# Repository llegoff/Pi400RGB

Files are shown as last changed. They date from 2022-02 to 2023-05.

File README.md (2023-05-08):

[:fr:](LISEZMOI.md) [:uk:](README.md)

# Pi400RGB
Scart/VGA interface for Raspberry Pi 400

Evolution of VGA_Zero (https://github.com/llegoff/VGA_Zero) and Pi400VGA (https://github.com/llegoff/Pi400VGA)

buy V2 on [ebay  :package: :credit_card:](https://www.ebay.fr/itm/404280189035)

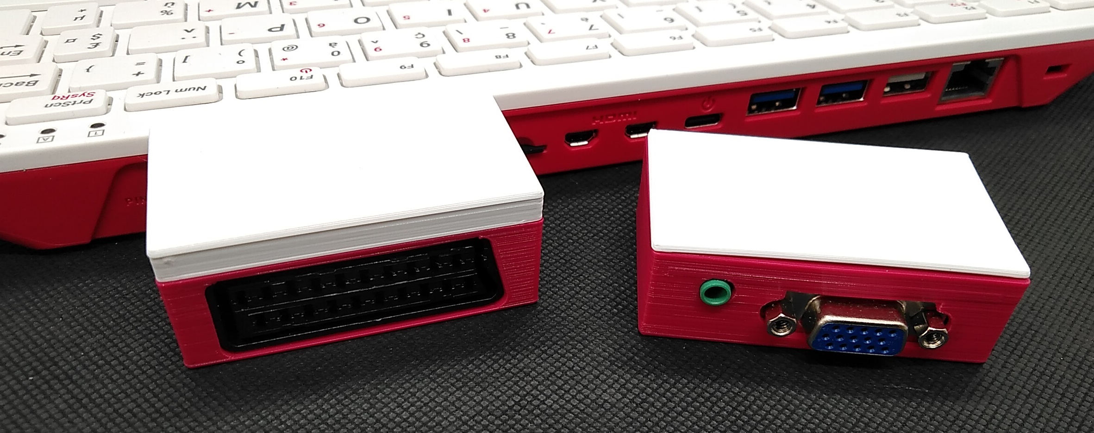
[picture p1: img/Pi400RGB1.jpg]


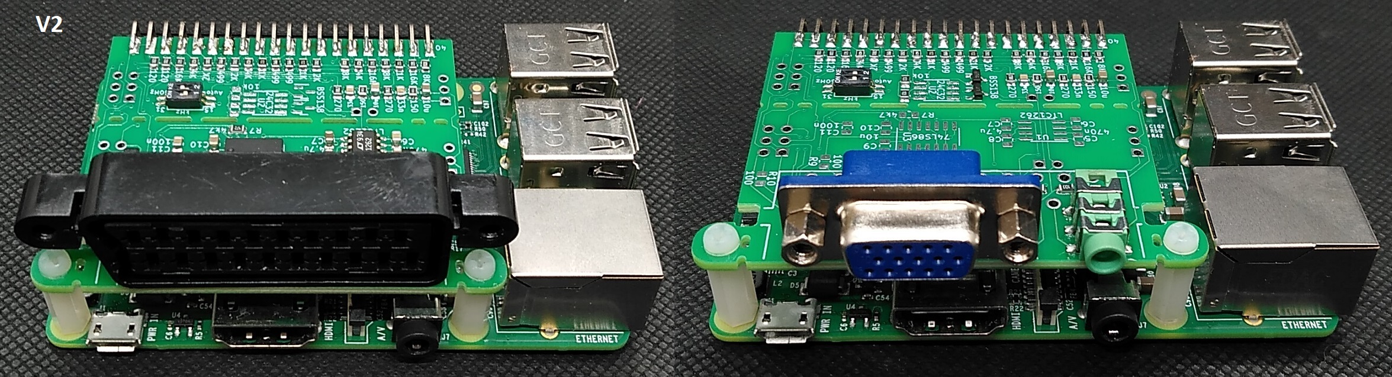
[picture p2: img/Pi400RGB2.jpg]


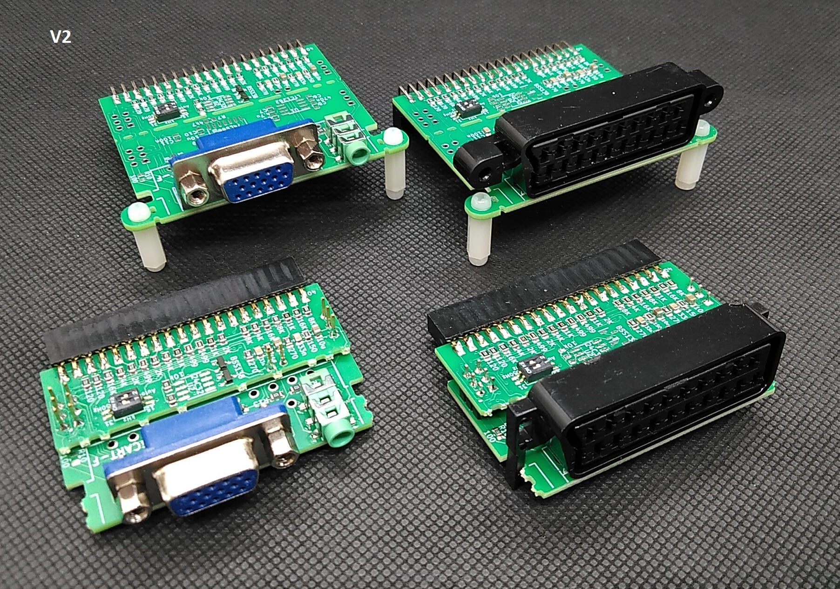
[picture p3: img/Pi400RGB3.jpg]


### DPI (Display parallel Interface)
Like [VGA666](https://github.com/fenlogic/vga666), this pcb uses dpi interface (in mode 6 to free gpio 18 & 19)

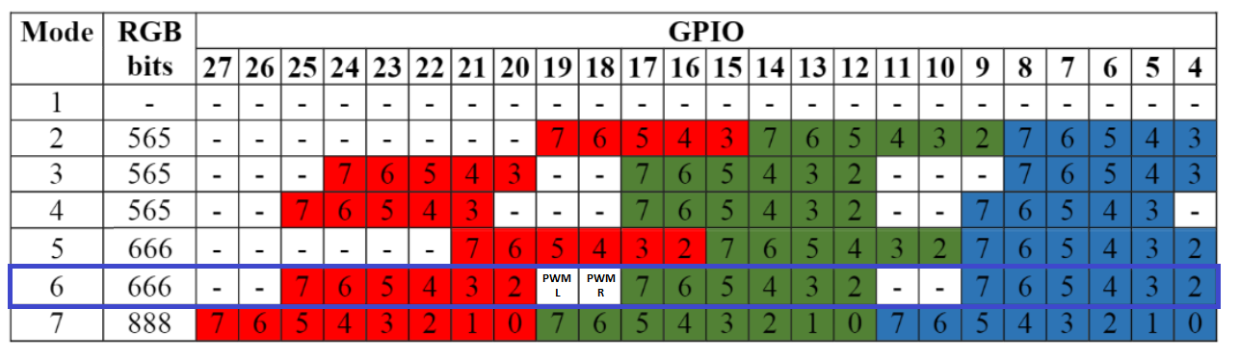
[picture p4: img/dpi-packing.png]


see https://www.raspberrypi.org/documentation/hardware/raspberrypi/dpi/README.md

only the necessary bits of the dpi are redirected to the 40-pin GPIO port, with the 'gpio=2-9,12-17,20-25=a2' line on config.txt

/boot/config.txt

    # disable i2c, pin use by h-sync & v-sync
    dtparam=i2c_arm=off
    # remplace dtoverlay=vc4-kms-v3d by
    dtoverlay=vc4-fkms-v3d
    #configuration DPI
    gpio=2-9,12-17,20-24=a2
    dpi_output_format=0x6
    enable_dpi_lcd=1
    display_default_lcd=1
    dpi_group=2
    dpi_mode=16
    #---------------- dpi_mode line VGA ---------------------
    #---> 640x480 60hz    dpi_mode=4
    #---> 800x600 60hz    dpi_mode=9
    #---> 1024x768 60hz   dpi_mode=16
    #---> 1280x768 60hz   dpi_mode=23
    #---> 1280x800 60hz   dpi_mode=28
    #---> 1280x960 60hz   dpi_mode=32
    #---> 1280x1024 60hz  dpi_mode=35
    #---> 1360x768 60hz   dpi_mode=39
    #---> 1366x768 60hz   dpi_mode=81
    #---> 1400x1050 60hz  dpi_mode=42
    #---> 1440x900 60hz   dpi_mode=47
    #---> 1600x1200 60hz  dpi_mode=51
    #---> 1680x1050 60hz  dpi_mode=58
    #---> 1920x1080 60hz  dpi_mode=82
    #---> 1920x1200 60hz  dpi_mode=69
    #---> 1920x1440 60hz  dpi_mode=73    
    #--------------- dpi_mode line SCART ------------------
    dpi_mode=87
    #240p@60
    #hdmi_timings=320 1 4 30 46 240 1 4 5 14 0 0 0 60 0 6400000 1
    #288p@50
    #hdmi_timings=384 1 16 32 40 288 1 3 2 19 0 0 0 50 0 7363200 1
    #576i@50
    hdmi_timings=768 1 24 72 88 576 1 6 5 38 0 0 0 50 1 14875000 1
    #480i@60
    #hdmi_timings=640 1 24 64 104 480 1 3 6 34 0 0 0 60 1 13054080 1
    #480p@60
    #hdmi_timings=640 1 24 96 48 480 1 11 2 32 0 0 0 60 0 25452000 1

Configuration working with vc4-kms-v3d

    dtoverlay=vc4-kms-dpi-generic,rgb666-padhi
    dtparam=hactive=768,hfp=24,hsync=72,hbp=88
    dtparam=vactive=576,vfp=6,vsync=5,vbp=38
    dtparam=clock-frequency=14875000
    #   Resolution@freq  hactive hfp hsync  hbp vactive vfp vsync vbp  clock-frequency
    #VGA   640x480  @60   640     16   96    48   480    10   2    33    25175000
    #SVGA  800x600  @60   800     40  128    88   600     1   4    23    40000000
    #XGA  1024x768  @60  1024     24  136   160   768     3   6    29    65000000
    #VESA 1368x768  @60  1368     72  144   216   768     1   3    23    85860000
    #VESA 1280x800  @60  1280     64  136   200   800     1   3    24    83460000
    #VESA 1280x1024 @60  1280     48  112   248  1024     1   3    38   108000000
    #VESA 1400x1050 @60  1400     88  152   240  1050     1   3    33   122660000
    #VESA 1600x1200 @60  1600     64  192   304  1200     1   3    46   162000000
    #--- TV -----
    #240p (NTSC res)@60   320      4   30    46   240     4   5    14     6400000
    #288p (PAL res) @50   384     16   32    40   288     3   2    19     7363200
    #480p           @60   640     24   96    48   480    11   2    32    25452000
    #720p           @60  1280    110   40   220   720     5   5    20    74250000
    #1080p          @60  1920     88   44   148  1080     4   5    36   148500000
    #more timming on http://tinyvga.com/vga-timing

### Audio Interface
audio interface is connected to gpio 18 & 19 (PWM)

/boot/config.txt

    # Enable audio for PiZero(loads snd_bcm2835)
    dtoverlay=audremap,pins_18_19
    dtparam=audio=on

### Recalbox

edit the config file /crt/recalbox-crt-options.cfg in the [RECALBOX] partition mounted when you plug the SD card in your computer:

see manual : https://www.recalbox.com/recalbox-rgb-dual/manual/

edit the config file /crt/recalbox-crt-options.cfg

    # Pour recalboxrgbdual
    adapter.type = recalboxrgbdual

the first boot can take 5 minutes

https://wiki.recalbox.com/en/tutorials/video/crt/recalbox-on-crt-with-scart-dac

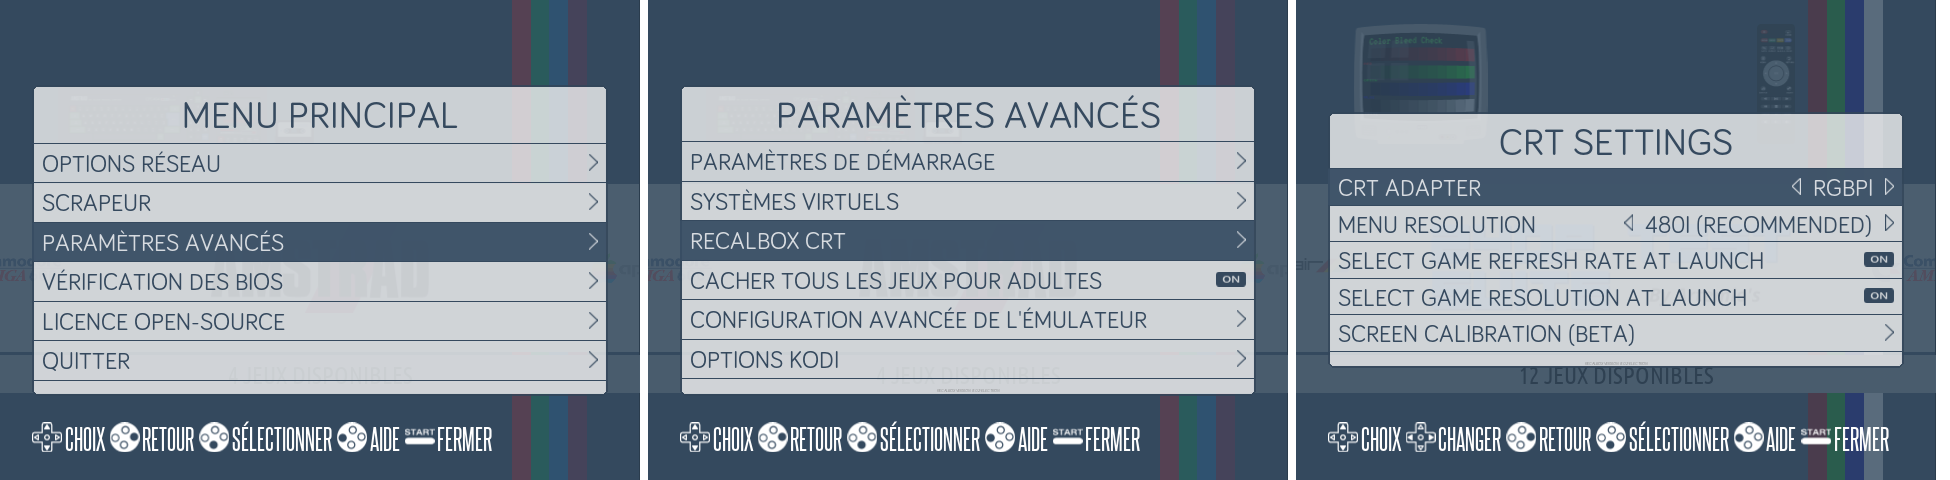
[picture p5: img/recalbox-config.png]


Add a jumper on V1 PCB

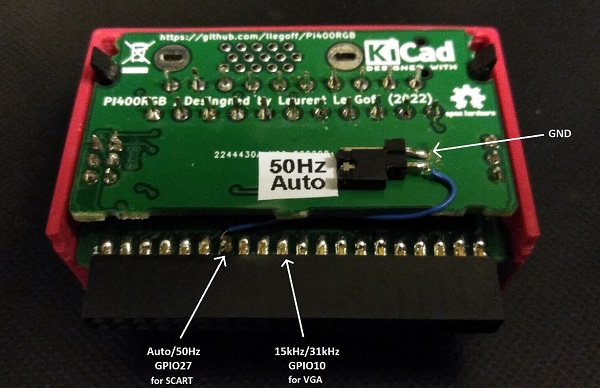
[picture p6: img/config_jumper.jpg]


## Schematic
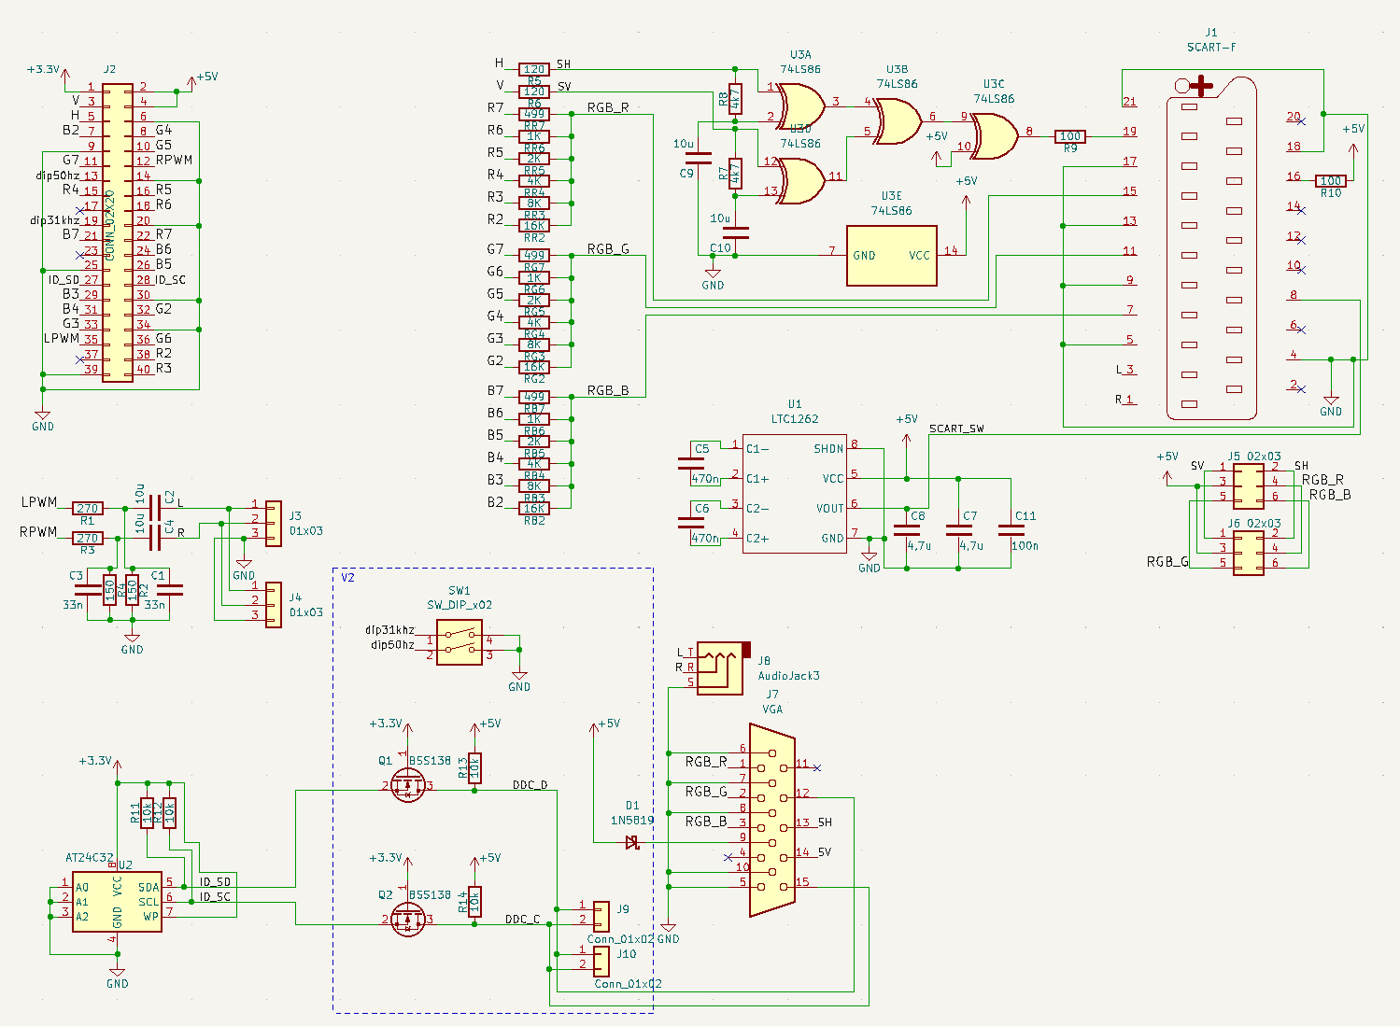
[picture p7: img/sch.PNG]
sch


## PCB
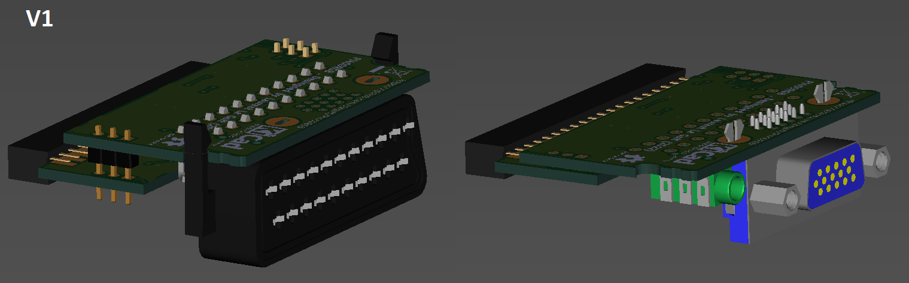
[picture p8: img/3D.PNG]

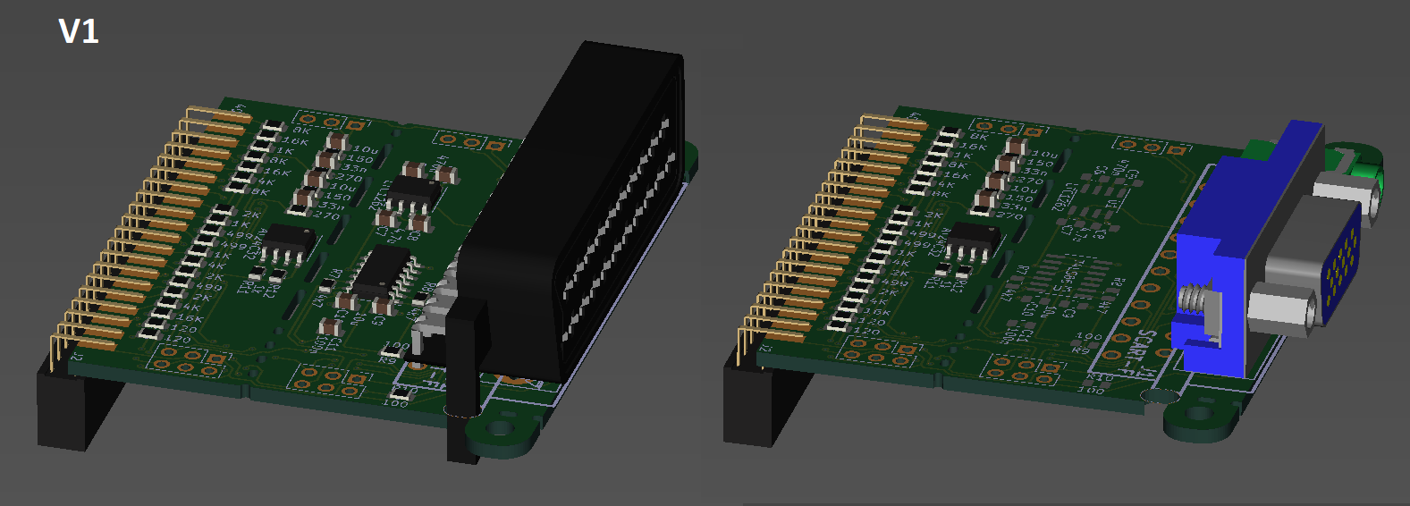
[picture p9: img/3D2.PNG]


## Installation
copy content of [config-example.txt](img/config-example.txt?raw=true) to /boot/config.txt

## Révision
rev1 : initial version

rev2 : add DDC on VGA connector and dip switch for recalbox configuration, coming soon

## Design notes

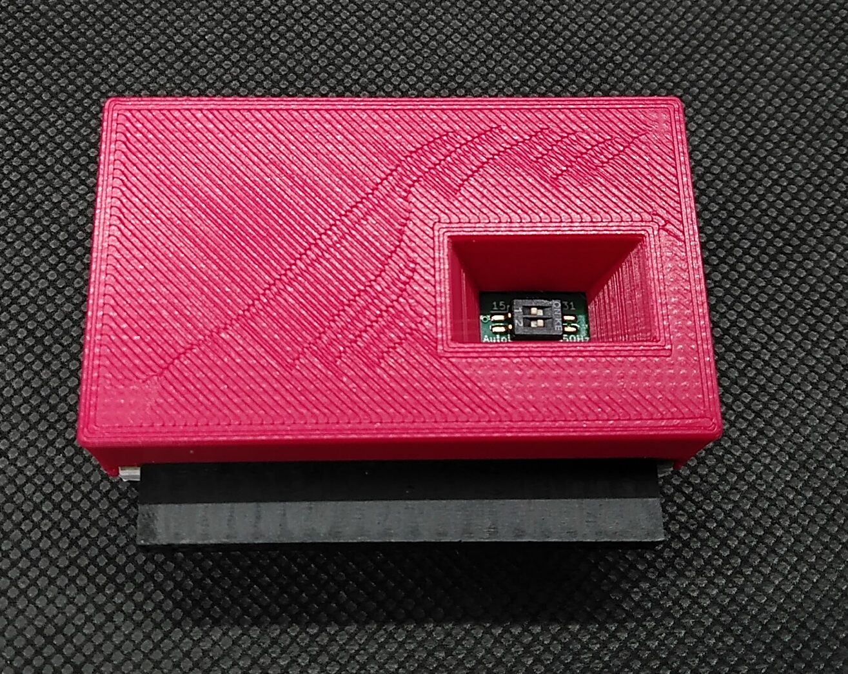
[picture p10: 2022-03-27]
img/PI400RGB5.jpg

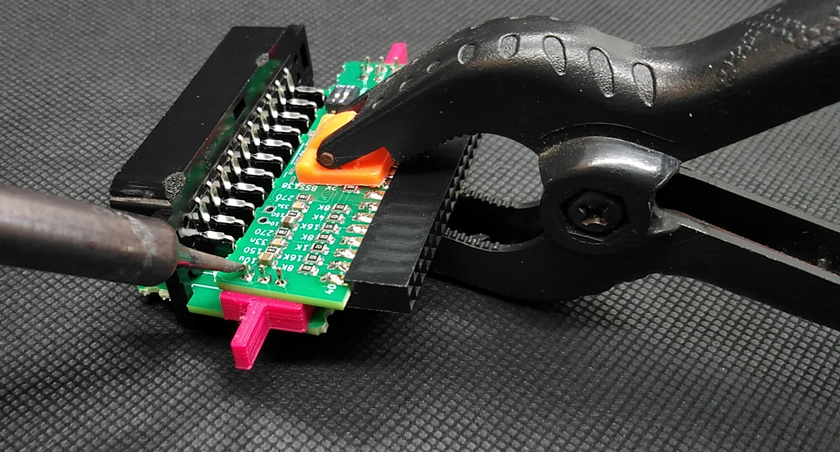
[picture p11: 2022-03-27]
img/PI400RGB4.jpg

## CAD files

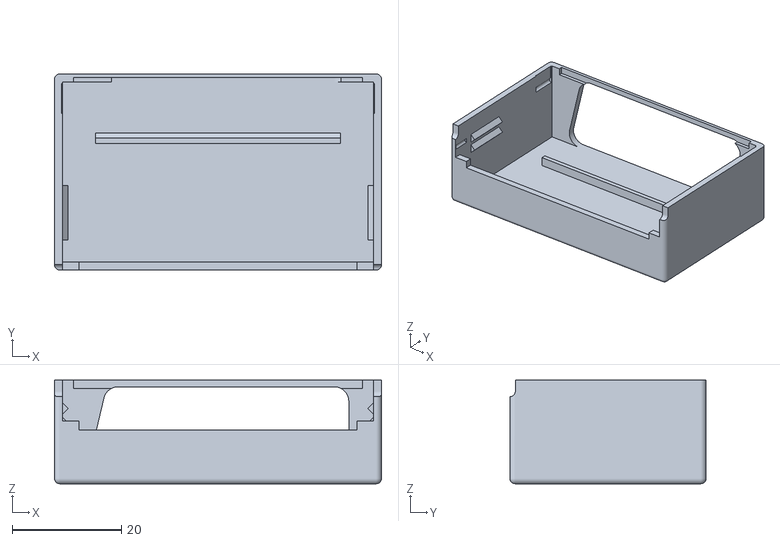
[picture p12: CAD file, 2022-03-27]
3D/Pi400RGB_SCARTbottom.stl
60.0 x 36.0 x 19.0

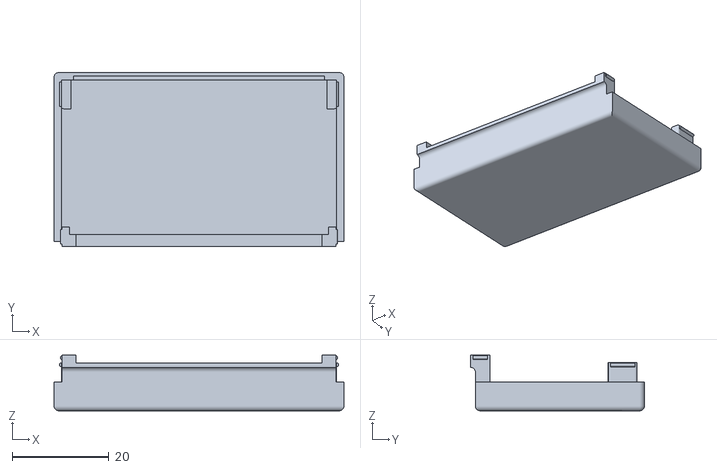
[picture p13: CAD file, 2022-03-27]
3D/Pi400RGB_SCARTtop.stl
60.0 x 36.0 x 11.5

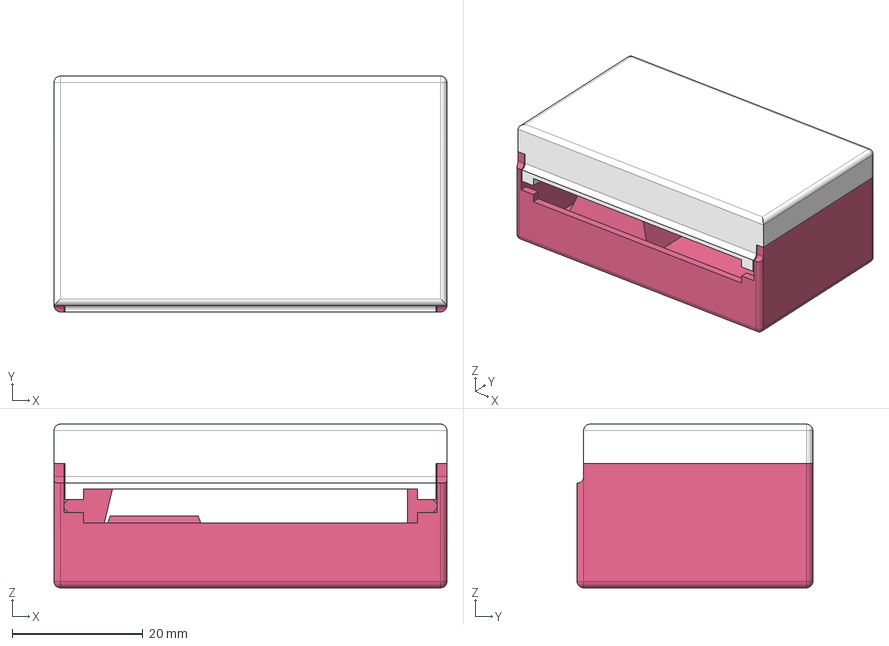
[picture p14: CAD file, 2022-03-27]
3D/Pi400RGB_Scart_V2.FCStd
60.0 x 36.0 x 25.0 mm

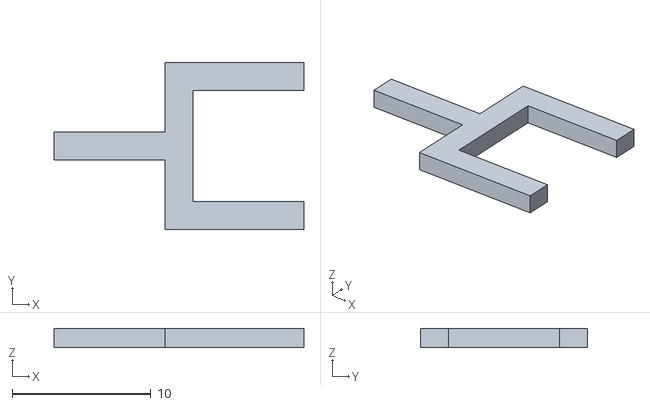
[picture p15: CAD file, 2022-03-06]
3D/VGA_Mounting_JIG.stl
18.0 x 12.0 x 1.40

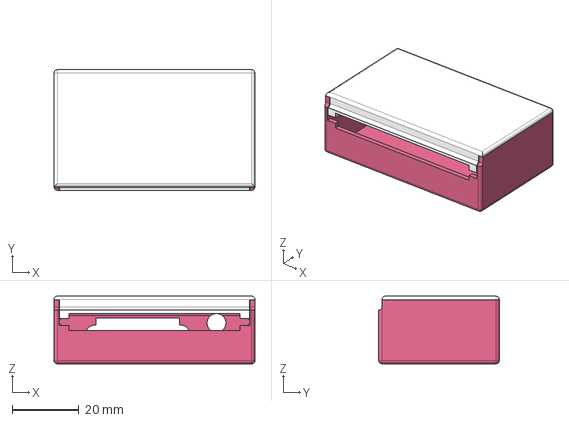
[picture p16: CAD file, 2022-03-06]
3D/Pi400RGB_VGA.FCStd
60.0 x 36.0 x 20.2 mm

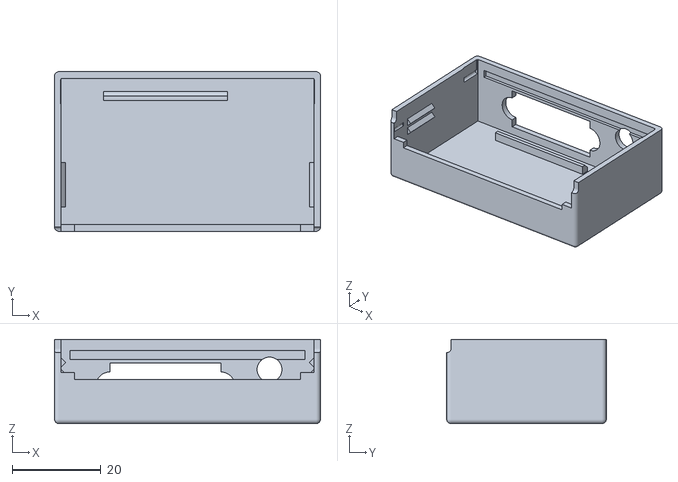
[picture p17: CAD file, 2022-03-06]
3D/Pi400RGB_VGAbottom.stl
60.0 x 36.0 x 19.0

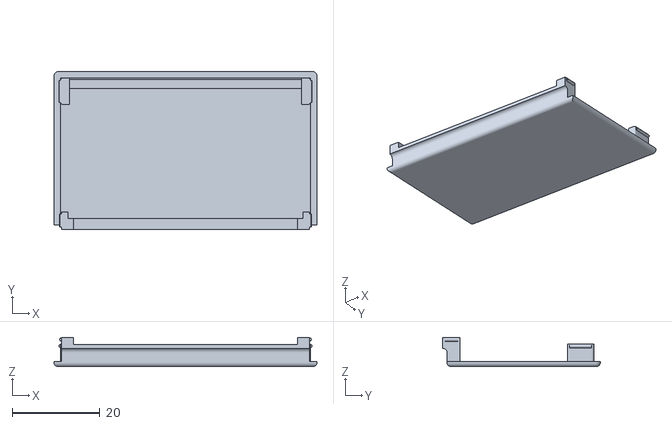
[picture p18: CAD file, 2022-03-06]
3D/Pi400RGB_VGAtop.stl
60.0 x 36.0 x 6.70

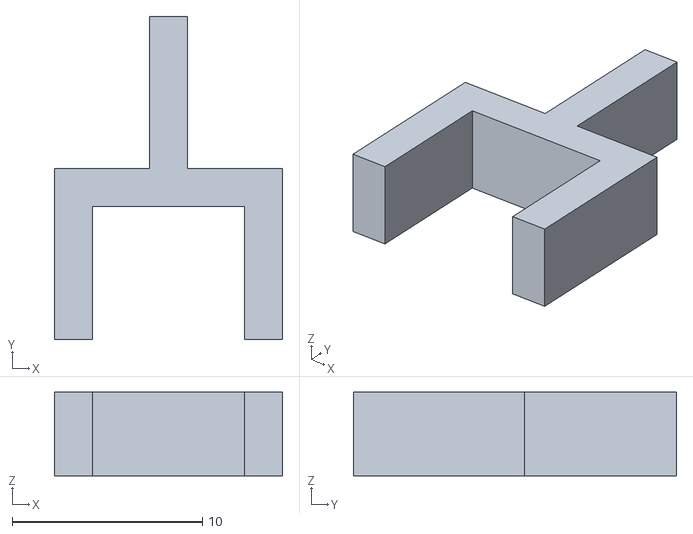
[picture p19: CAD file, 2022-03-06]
3D/Scart_Mounting_JIG.stl
12.0 x 17.0 x 4.40

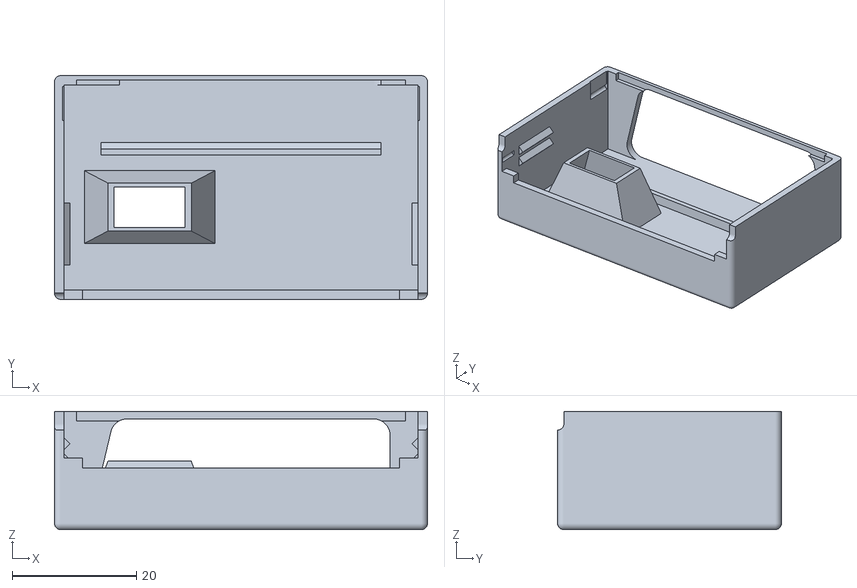
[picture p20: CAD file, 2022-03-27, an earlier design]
3D/Pi400RGB_SCARTbottomV2.stl
60.0 x 36.0 x 19.0

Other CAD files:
3D/Pi400RGB_Scart.FCStd

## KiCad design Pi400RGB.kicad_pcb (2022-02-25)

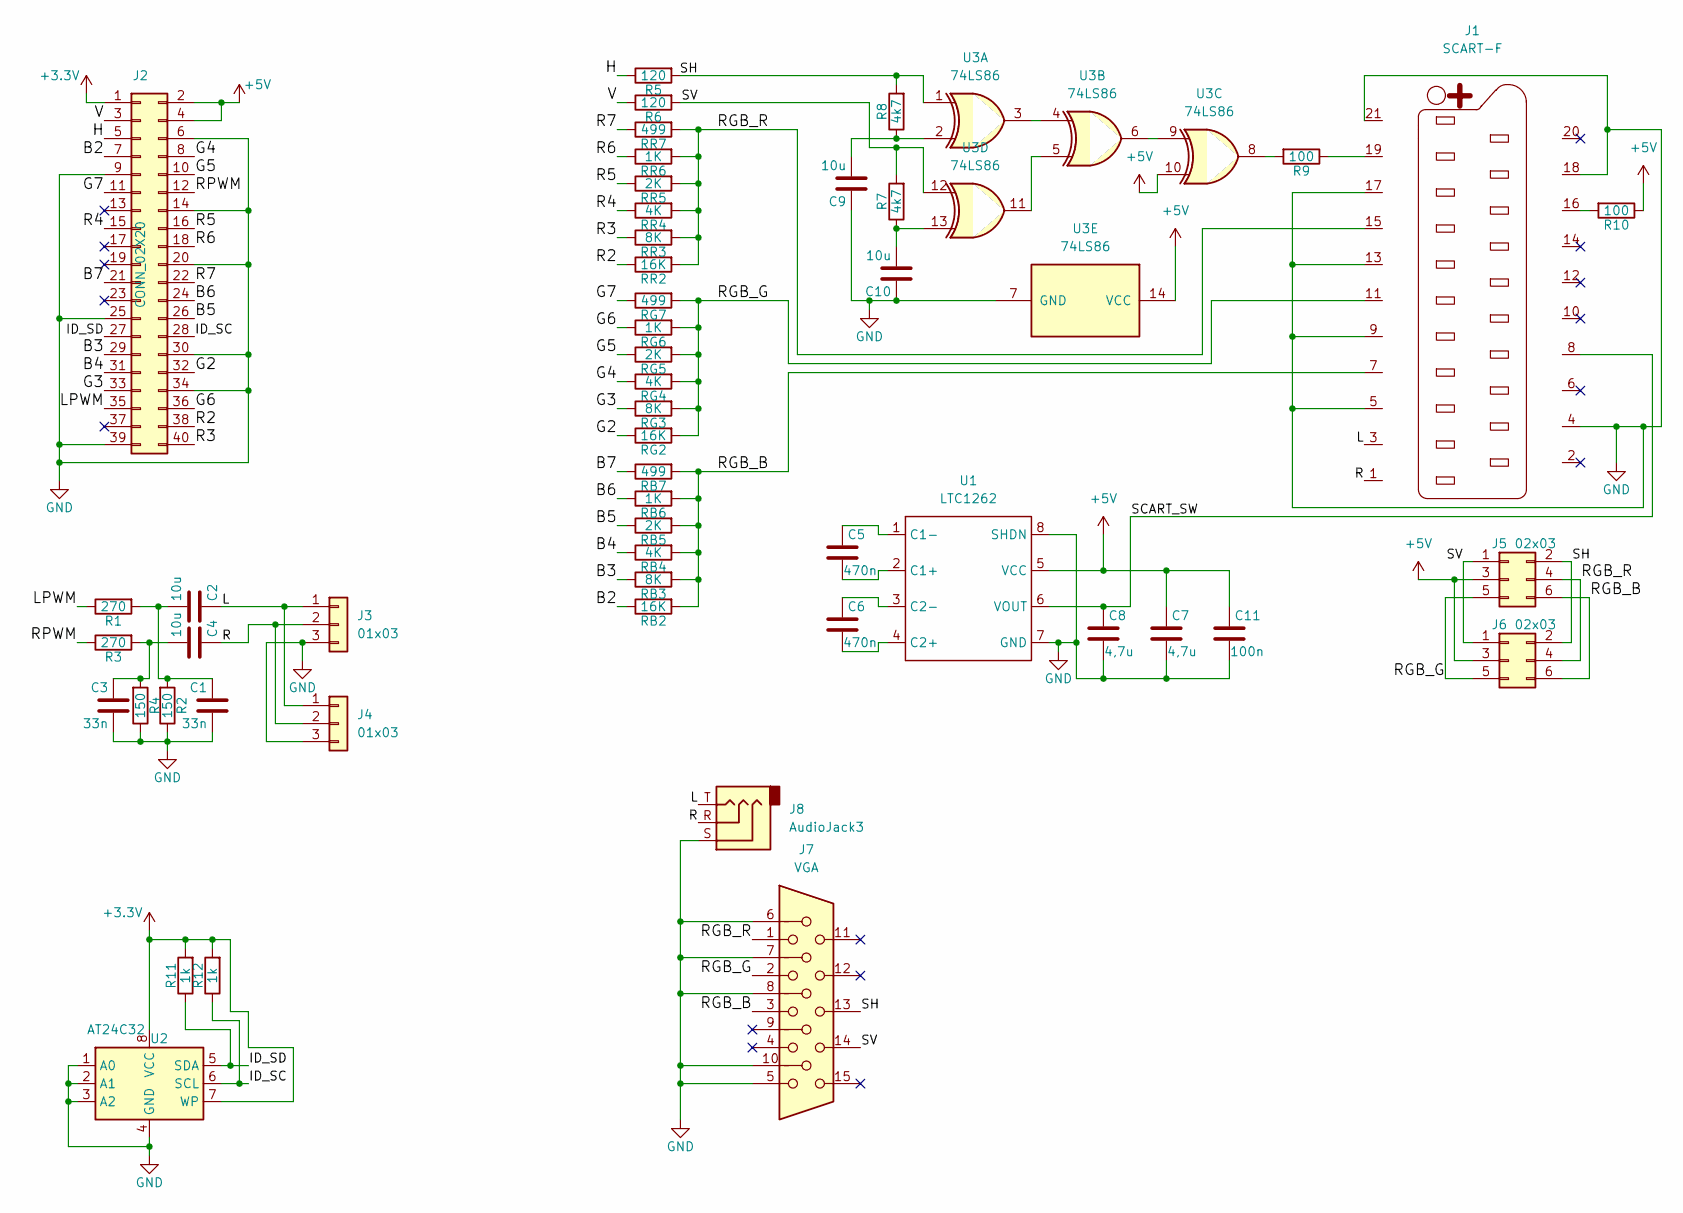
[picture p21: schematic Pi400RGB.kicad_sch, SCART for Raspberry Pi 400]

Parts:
C1, C3: 33n; C_0805_2012Metric
C2, C4, C9, C10: 10u; C_0805_2012Metric
C5, C6: 470n; C_0805_2012Metric
C7, C8: 4,7u; C_0805_2012Metric
C11: 100n; C_0805_2012Metric
J1: SCART-F; SCART
J2: CONN_02X20; 2x40_PCB
J3, J4: 01x03; PinHeader_1x03_P2.54mm_Vertical
J5, J6: 02x03; PinHeader_2x03_P2.54mm_Vertical
J7: VGA; DB_15F-VGA
J8: AudioJack3; jack3.5smd
R1, R3: 270; R_0805_2012Metric
R2, R4: 150; R_0805_2012Metric
R5, R6: 120; R_0805_2012Metric
R7, R8: 4k7; R_0805_2012Metric
R9, R10: 100; R_0805_2012Metric
R11, R12: 1k; R_0805_2012Metric
RB2: 16K; R_0805_2012Metric
RB3: 8K; R_0805_2012Metric
RB4: 4K; R_0805_2012Metric
RB5: 2K; R_0805_2012Metric
RB6: 1K; R_0805_2012Metric
RB7: 499; R_0805_2012Metric
RG2: 16K; R_0805_2012Metric
RG3: 8K; R_0805_2012Metric
RG4: 4K; R_0805_2012Metric
RG5: 2K; R_0805_2012Metric
RG6: 1K; R_0805_2012Metric
RG7: 499; R_0805_2012Metric
RR2: 16K; R_0805_2012Metric
RR3: 8K; R_0805_2012Metric
RR4: 4K; R_0805_2012Metric
RR5: 2K; R_0805_2012Metric
RR6: 1K; R_0805_2012Metric
RR7: 499; R_0805_2012Metric
U1: LTC1262; SOIC-8_3.9x4.9mm_P1.27mm
U2: AT24C32; SOIC-8_3.9x4.9mm_P1.27mm
U3: 74LS86; SOIC-14_3.9x8.7mm_P1.27mm

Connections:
+3V3: J2.1, R11.2, R12.2, U2.7 (WP), U2.8 (VCC)
+5V: C7.1, C11.1, J2.2, J2.4, J5.3, J6.3, R10.1, U1.5 (VCC), U3.10, U3.14 (VCC)
/B2: J2.7, RB2.1
/B3: J2.29, RB3.1
/B4: J2.31, RB4.1
/B5: J2.26, RB5.1
/B6: J2.24, RB6.1
/B7: J2.21, RB7.1
/G2: J2.32, RG2.1
/G3: J2.33, RG3.1
/G4: J2.8, RG4.1
/G5: J2.10, RG5.1
/G6: J2.36, RG6.1
/G7: J2.11, RG7.1
/H: J2.5, R5.1
/ID_SC: J2.28, R12.1, U2.6 (SCL)
/ID_SD: J2.27, R11.1, U2.5 (SDA)
/L: C2.1, J1.3, J3.1, J4.1, J8.T
/LPWM: J2.35, R1.1
/R: C4.1, J1.1, J3.2, J4.2, J8.R
/R2: J2.38, RR2.1
/R3: J2.40, RR3.1
/R4: J2.15, RR4.1
/R5: J2.16, RR5.1
/R6: J2.18, RR6.1
/R7: J2.22, RR7.1
/RGB_B: J1.7, J5.6, J6.6, J7.3, RB2.2, RB3.2, RB4.2, RB5.2, RB6.2, RB7.2
/RGB_G: J1.11, J5.5, J6.5, J7.2, RG2.2, RG3.2, RG4.2, RG5.2, RG6.2, RG7.2
/RGB_R: J1.15, J5.4, J6.4, J7.1, RR2.2, RR3.2, RR4.2, RR5.2, RR6.2, RR7.2
/RPWM: J2.12, R3.1
/SCART_SW: C8.1, J1.8, U1.6 (VOUT)
/SH: J5.2, J6.2, J7.13, R5.2, R8.2, U3.1
/SV: J5.1, J6.1, J7.14, R6.2, R7.2, U3.12
/V: J2.3, R6.1
GND: C1.2, C3.2, C7.2, C8.2, C9.1, C10.1, C11.2, J1.4, J1.5, J1.9, J1.13, J1.17, J1.18, J1.21, J2.6, J2.9, J2.14, J2.20, J2.25, J2.30, J2.34, J2.39, J3.3, J4.3, J7.5, J7.6, J7.7, J7.8, J7.10, J8.S, R2.1, R4.1, U1.7 (GND), U1.8 (SHDN), U2.1 (A0), U2.2 (A1), U2.3 (A2), U2.4 (GND), U3.7 (GND)
unnamed: C1.1, C2.2, R1.2, R2.2
unnamed: C3.1, C4.2, R3.2, R4.2
unnamed: C5.1, U1.1 (C1-)
unnamed: C5.2, U1.2 (C1+)
unnamed: C6.1, U1.3 (C2-)
unnamed: C6.2, U1.4 (C2+)
unnamed: C9.2, R8.1, U3.2
unnamed: C10.2, R7.1, U3.13
unnamed: J1.16, R10.2
unnamed: J1.19, R9.1
unnamed: R9.2, U3.8
unnamed: U3.3, U3.4
unnamed: U3.6, U3.9
unnamed: U3.5, U3.11

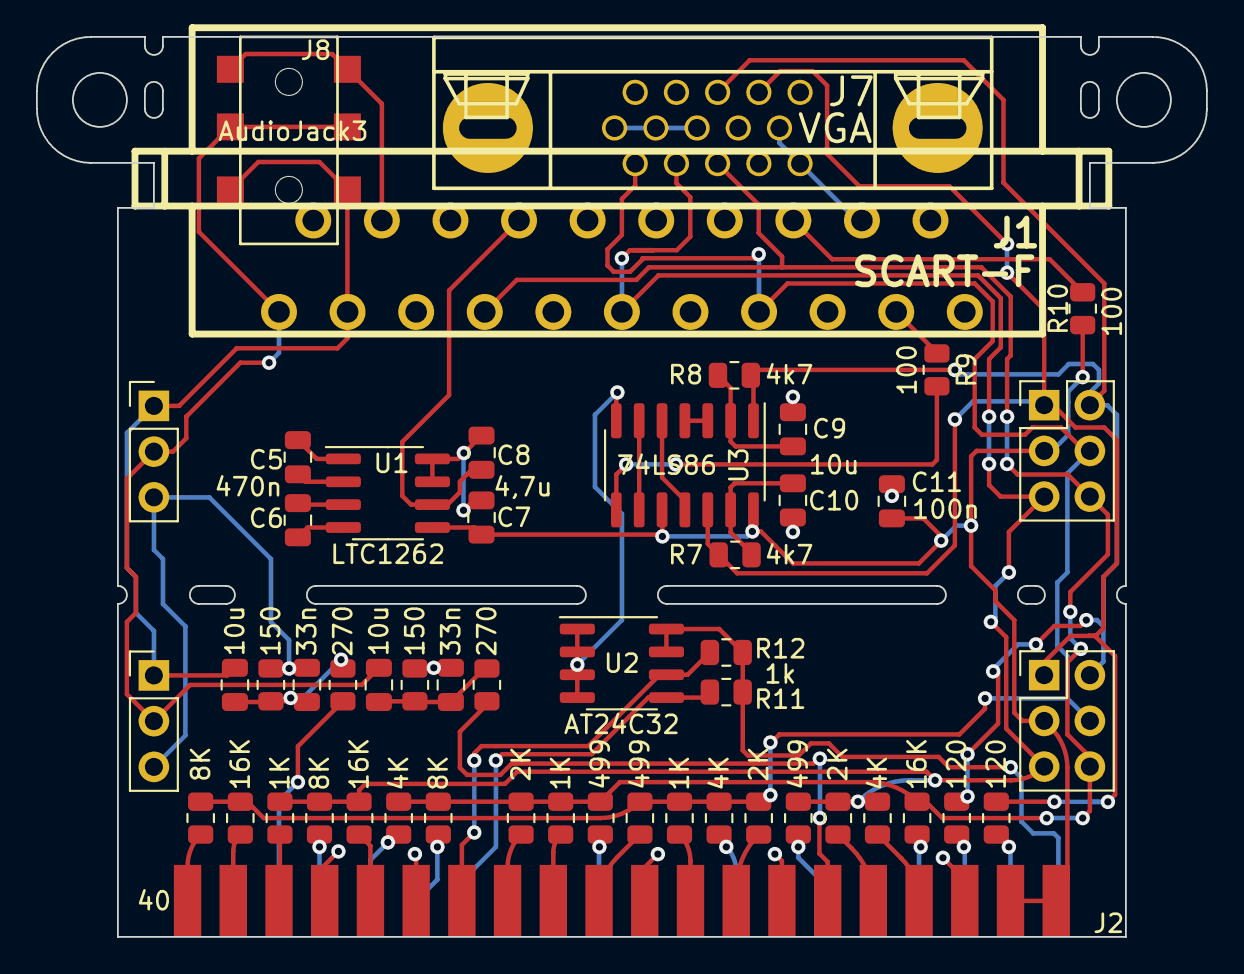
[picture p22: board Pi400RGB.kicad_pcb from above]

Board: 2 copper layers, 65.0 x 50.0 mm, 52 parts (0 on the bottom side), 49 nets.

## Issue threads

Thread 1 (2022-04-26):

contacting you

britxpatusa, 2022-04-26:
hello - im trying to get the VGA adapter working but having no luck on a P400 or Pi4.
can you help?

llegoff, 2022-04-27:
Hello,
what OS are you trying to run the interface on?
Raspberry pi OS, Recalbox OS, RGBpi OS, ... ?
What screen are you using? what resolution?

Cordially
Laurent

britxpatusa, 2022-04-27:
[config.txt](https://github.com/llegoff/Pi400RGB/files/8571998/config.txt)

britxpatusa, 2022-04-27:
quick update on this:
sound is working through the adapter
HDMI is working
VGA still no signal

llegoff, 2022-04-27:
Overlay vc4-kms-dpi-generic work with vc4-kms-v3d (not with vc4-fkms-v3d)

modify

[pi4]
# Enable DRM VC4 V3D driver on top of the dispmanx display stack
dtoverlay=vc4-fkms-v3d
max_framebuffers=2

by

[pi4]
# Enable DRM VC4 V3D driver on top of the dispmanx display stack
dtoverlay=vc4-kms-v3d
max_framebuffers=2

erase 2 line
gpio=0-1=a2
gpio=2-8,12-17,20-24=a2

this is already configured by the overlay vc4-kms-dpi-generic

the vc4-vga666 overlay (https://github.com/Cpasjuste/rpi-dpidac) can also be used with the mode6 option

I don't know CoinOPS, I download it to test

britxpatusa, 2022-04-27:
awesome ill give that a go thanks!

llegoff, 2022-04-27:
I tested CoinOPS, but my gamepad does not work.
below are the 2 configs that work

configuration working with the vc4-kms-v3d overlay
```
# For more options and information see
# http://rpf.io/configtxt
# Some settings may impact device functionality. See link above for details

# uncomment if you get no picture on HDMI for a default "safe" mode
#hdmi_safe=1

# Disable rainbow image at boot
disable_splash=1

# uncomment the following to adjust overscan. Use positive numbers if console
# goes off screen, and negative if there is too much border
#overscan_left=16
#overscan_right=16
#overscan_top=16
#overscan_bottom=16

# uncomment to force a console size. By default it will be display's size minus
# overscan.
#framebuffer_width=1280
#framebuffer_height=720

# uncomment if hdmi display is not detected and composite is being output
#hdmi_force_hotplug=1

# uncomment to force a specific HDMI mode (this will force VGA)
#hdmi_group=1
#hdmi_mode=16

# uncomment to force a HDMI mode rather than DVI. This can make audio work in
# DMT (computer monitor) modes
#hdmi_drive=2

# uncomment to increase signal to HDMI, if you have interference, blanking, or
# no display
#config_hdmi_boost=4

# uncomment for composite PAL
#sdtv_mode=2

#uncomment to overclock the arm. 700 MHz is the default.
#arm_freq=2100
#v3d_freq=850
#over_voltage=7

# Uncomment some or all of these to enable the optional hardware interfaces
#dtparam=i2c_arm=on
#dtparam=i2s=on
#dtparam=spi=on

# Uncomment this to enable infrared communication.
#dtoverlay=gpio-ir,gpio_pin=17
#dtoverlay=gpio-ir-tx,gpio_pin=18

# Additional overlays and parameters are documented /boot/overlays/README

# Enable audio (loads snd_bcm2835)
dtparam=audio=on

# Automatically load overlays for detected cameras
camera_auto_detect=1

# Automatically load overlays for detected DSI displays
display_auto_detect=1

# Enable DRM VC4 V3D driver
dtoverlay=vc4-kms-v3d
max_framebuffers=2

# Run in 64-bit mode
arm_64bit=1

# Disable compensation for displays with overscan
disable_overscan=1

[cm4]
# Enable host mode on the 2711 built-in XHCI USB controller.
# This line should be removed if the legacy DWC2 controller is required
# (e.g. for USB device mode) or if USB support is not required.
otg_mode=1

[all]

[pi4]
# Run as fast as firmware / board allows
#arm_boost=1

[all]
enable_uart=1

# Enable audio on GPIO for Pi400
dtoverlay=audremap,pins_18_19
dtparam=audio=on

dtoverlay=vc4-kms-dpi-generic,rgb666-padhi
dtparam=hactive=320,hfp=4,hsync=30,hbp=46
dtparam=vactive=240,vfp=4,vsync=5,vbp=14
dtparam=clock-frequency=6400000

```
I note that with the vc4-dpi-generic overlay does not manage interlaced resolution

configuration working with the vc4-fkms-v3d overlay
```
# For more options and information see
# http://rpf.io/configtxt
# Some settings may impact device functionality. See link above for details

# uncomment if you get no picture on HDMI for a default "safe" mode
#hdmi_safe=1

# Disable rainbow image at boot
disable_splash=1

# uncomment the following to adjust overscan. Use positive numbers if console
# goes off screen, and negative if there is too much border
#overscan_left=16
#overscan_right=16
#overscan_top=16
#overscan_bottom=16

# uncomment to force a console size. By default it will be display's size minus
# overscan.
#framebuffer_width=1280
#framebuffer_height=720

# uncomment if hdmi display is not detected and composite is being output
#hdmi_force_hotplug=1

# uncomment to force a specific HDMI mode (this will force VGA)
#hdmi_group=1
#hdmi_mode=16

# uncomment to force a HDMI mode rather than DVI. This can make audio work in
# DMT (computer monitor) modes
#hdmi_drive=2

# uncomment to increase signal to HDMI, if you have interference, blanking, or
# no display
#config_hdmi_boost=4

# uncomment for composite PAL
#sdtv_mode=2

#uncomment to overclock the arm. 700 MHz is the default.
#arm_freq=2100
#v3d_freq=850
#over_voltage=7

# Uncomment some or all of these to enable the optional hardware interfaces
#dtparam=i2c_arm=on
#dtparam=i2s=on
#dtparam=spi=on

# Uncomment this to enable infrared communication.
#dtoverlay=gpio-ir,gpio_pin=17
#dtoverlay=gpio-ir-tx,gpio_pin=18

# Additional overlays and parameters are documented /boot/overlays/README

# Enable audio (loads snd_bcm2835)
dtparam=audio=on

# Automatically load overlays for detected cameras
camera_auto_detect=1

# Automatically load overlays for detected DSI displays
display_auto_detect=1

# Enable DRM VC4 V3D driver
dtoverlay=vc4-fkms-v3d
max_framebuffers=2

# Run in 64-bit mode
arm_64bit=1

# Disable compensation for displays with overscan
disable_overscan=1

[cm4]
# Enable host mode on the 2711 built-in XHCI USB controller.
# This line should be removed if the legacy DWC2 controller is required
# (e.g. for USB device mode) or if USB support is not required.
otg_mode=1

[all]

[pi4]
# Run as fast as firmware / board allows
#arm_boost=1

[all]
enable_uart=1

# Enable audio on GPIO for Pi400
dtoverlay=audremap,pins_18_19
dtparam=audio=on

# DPI
# disable i2c, pin use by h-sync & v-sync
dtparam=i2c_arm=off
gpio=2-9,12-17,20-24=a2
dpi_output_format=0x6
enable_dpi_lcd=1
display_default_lcd=1
dpi_group=2
dpi_mode=87
#244p@60
hdmi_timings=320 1 4 30 46 240 1 4 5 14 0 0 0 60 0 6400000 1
#288p@50
#hdmi_timings=384 1 16 32 40 288 1 3 2 19 0 0 0 50 0 7363200 1
#576i@50
#hdmi_timings=768 1 24 72 88 576 1 6 5 38 0 0 0 50 1 14875000 1
#480i@60
#hdmi_timings=640 1 24 64 104 480 1 3 6 34 0 0 0 60 1 13054080 1
#480p@60
#hdmi_timings=640 1 24 96 48 480 1 11 2 32 0 0 0 60 0 25452000 1
```

britxpatusa, 2022-04-27:
ok i will try now! thanks for looking at this!

llegoff, 2022-04-27:
I don't have the sound either on CoinOPS, but I have it on RaspberrypiOS with the same config

I saw in a CoinOPS documentation that the sound is by default on hdmi

there is probably a menu to activate the sound on the jack, but I do not have a controller compatible with CoinOPS, I do not have access to the menu

britxpatusa, 2022-04-27:
thanks i had the sound working through the adapter..the coinops build is HDMI only v3 will allow other...
Are there any other options in terms of hdmi timings i can try?
I have tried all of these by uncommenting each one(#)
Im using a VGA to RGB adpater to the CRT tv (NTSC) USA tv

llegoff, 2022-04-27:
on the Recalbox wiki page there is a list of hdmi_timmings to test :
https://wiki.recalbox.com/en/tutorials/video/crt/crt-screen-dpi-vga666-piscart-rgbpi

pi400RGB works well with Recalbox:
https://wiki.recalbox.com/en/tutorials/video/crt/recalbox-on-crt-with-scart-dac

britxpatusa, 2022-04-27:
Thanks does the adapter work with a vga to rgb cable?

________________________________
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

llegoff, 2022-04-28:
There are 3 types of vga to RGB cables:
- VGA -> 5 RCA or BNC ( R + G + B + Hsync + Vsync)  this type of cable works
- VGA -> 4 RCA or BNC ( R + G + B + Csync) this type of cable has a good chance of working
- VGA -> 3 RCA or BNC ( R + G/Csync +B) this type of cable will only work if it contains components to combine the G+Hsync+Vsync signals on the same connector

britxpatusa, 2022-04-28:
Hey thanks for all your help!

I have this cable but happy to buy another

Amazon.com: Zerone 5FT/ 1.5M VGA to 3 RCA Cable, VGA Male Plug 15 pin to TV S-Video 3 RCA PC Computer AV Adapter Cable for HDTV PC DVD Laptop : Electronics <https://www.amazon.com/gp/product/B07F3WVV99/ref=ppx_yo_dt_b_search_asin_title?ie=UTF8&psc=1>

The CRT im trying to use it with has composite R/G/B or I can use component(Y)

Would I be better getter your SCART adapter and using a scart to RGB cable?

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

llegoff, 2022-04-28:
CT-27SL15 seems to have a YPbPr input, and cable is VGA to YPbPr, its good
this cable contains components to convert RGB (VGA) to YPbPr
Y=0,299*R+0,587*G+0,114*B+Csync
Pb=-0,168*R-0,331*G+0,5*B
pr=0,5*R-0,418*G-0,081*B

in europe we did not have YPbPr socket on CRT TVs, but a SCART socket with RGB input

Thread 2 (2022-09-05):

Is the LTC1262 not needed?

bassybeats, 2022-09-05:
Hi, I am trying to source the parts for this and the LTC1262's are not easily found at the moment. Am I reading it correctly that its not needed if you don't need function switching? Some of the photos don't have it installed. Or is there a readily available alternative.

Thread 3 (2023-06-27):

Recallbox + Sony PVM monitor not working with Pi400RGB

belzrebuth, 2023-06-27:
Hi!
I'm trying to make this adapter work with a fresh install of Recallbox.
Only thing I've changed as per the instructions here was to add these lines in the options file
# Pour recalboxrgbdual
adapter.type = recalboxrgbdual
The adapter is set to AUTO since the monitor supports 60Hz.
Should I do anything more for it to work?
I get no picture..

belzrebuth, 2023-06-27:
I had to remove the EPROM and the two 1k resistors next to it in order to get a picture? Does this make any sense?Should I try a new EPROM IC in there?
I now get a picture so either there was something wrong with that chip or it's not needed at all?!
